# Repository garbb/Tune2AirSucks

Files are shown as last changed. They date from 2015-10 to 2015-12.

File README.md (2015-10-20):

# Tune2AirSucks
This is an attempt to create an interface between the 30pin ipod connector in my car and bluetooth so that I can stream audio from my phone. There exist several commercial products that perform this function, however none of the ones I could find supported displaying song information on my stereo.

It uses a [teensy 3.1](https://www.pjrc.com/teensy/teensy31.html) arduino-comptable board connected to a [BC127 chip] (https://www.sparkfun.com/products/12819) to manage the bluetooth connection.

It will support audio streaming over A2DP and remote control over AVRCP and also transmit song title/artist/album metadata if your phone has AVRCP 1.3 or greater.

The arduino folder contains code to be written to the Teensy with the arduino IDE.<br>
The eagle folder contains schematics and board files needed to make the PCB.<br>
The test folder contains random testing/debugging code such as "ipod.dock.sniffer" which is for sniffing the traffic between an ipod and a dock so I could figure out how it worked.

<br>
Some code/knowledge borrowed/stolen from the following:
* Arduino library for controlling ipods: https://github.com/finsprings/arduinaap<br>
* Purpletooth Jamboree (used for prototyping and used eagle files for audio circuit) https://www.sparkfun.com/products/11924
* BC127 Bluetooth chip arduino library from sparkfun: https://github.com/sparkfun/SparkFun_BC127_Bluetooth_Module_Arduino_Library/

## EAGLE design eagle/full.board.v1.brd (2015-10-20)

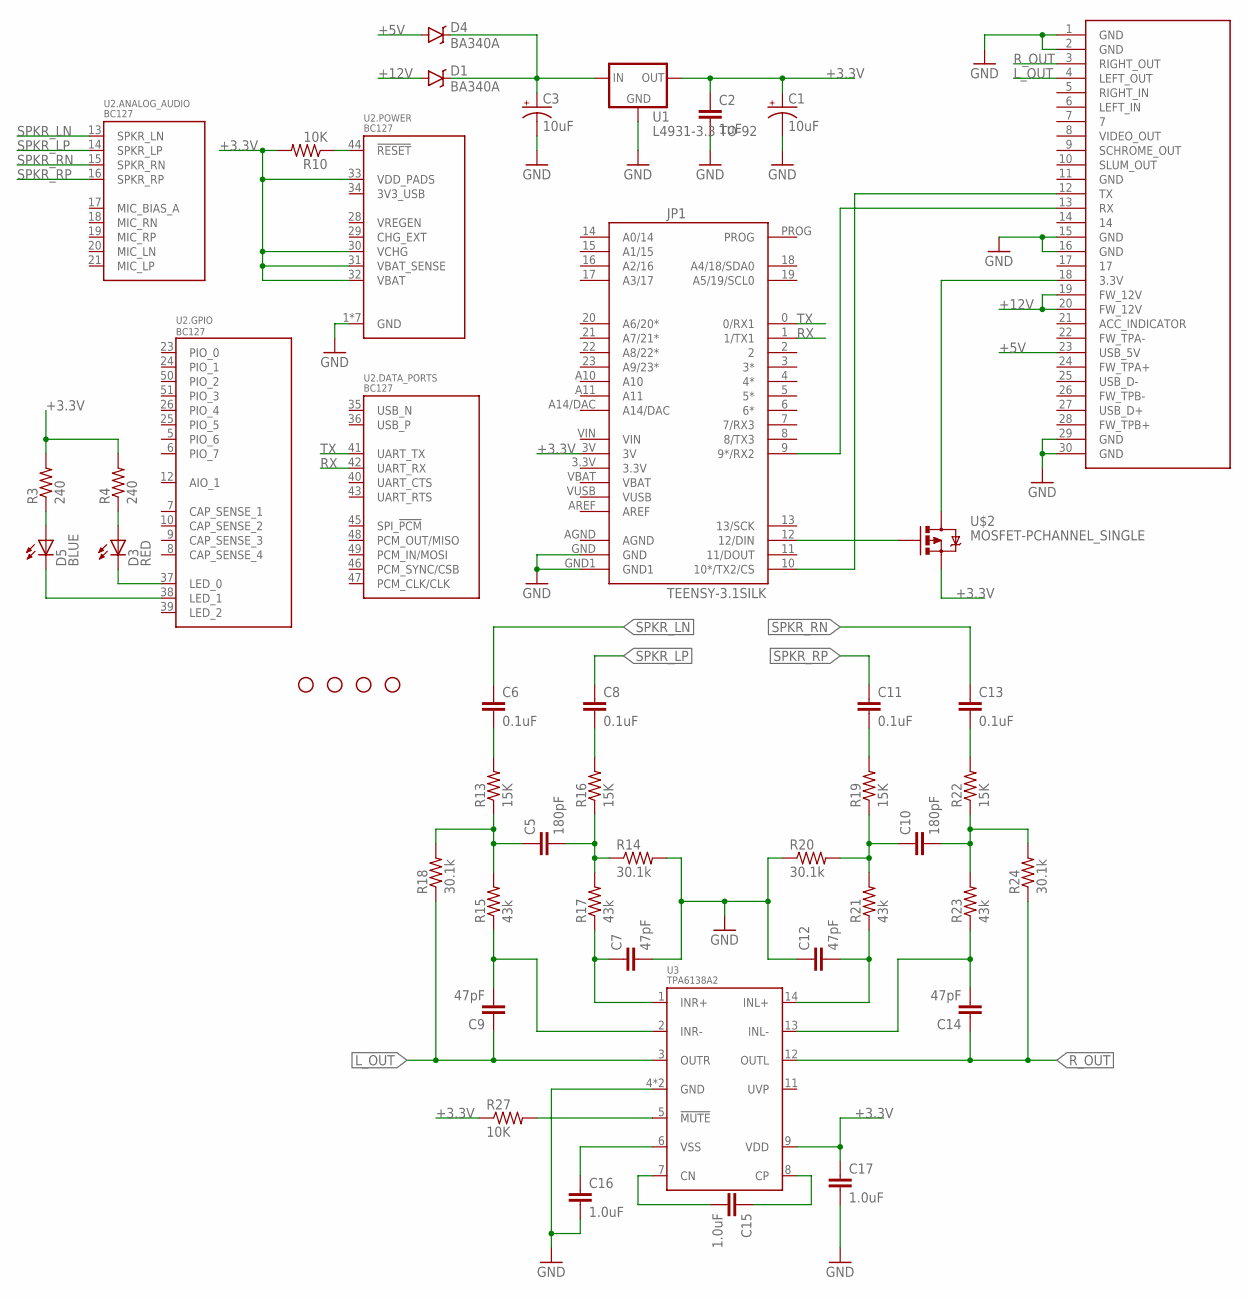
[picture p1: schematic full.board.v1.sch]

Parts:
C1, C3: 10uF; EIA3216
C2: 1uF; 0805
C5, C10: 180pF; 0603-CAP
C6, C8, C11, C13: 0.1uF; 0603-CAP
C7, C9, C12, C14: 47pF; 0603-CAP
C15, C16, C17: 1.0uF; 0603-CAP
D1, D4: BA340A; SMA-DIODE
D3: RED; LED-0603
D5: BLUE; LED-0603
IPOD_CONNECTOR_FEMALE: IPOD_CONNECTOR_FEMALECUTOUT; IPOD_FEM_SM_CUTOUTS
JP1: TEENSY-3.1SILK; TEENSY-3.1
R3, R4: 240; 0603-RES
R10, R27: 10K; 0603-RES
R13, R16, R19, R22: 15K; 0603-RES
R14, R18, R20, R24: 30.1k; 0603-RES
R15, R17, R21, R23: 43k; 0603-RES
STANDOFF1, STANDOFF2, STANDOFF3, STANDOFF4: STAND-OFF
U1: L4931-3.3 TO-92; TO-92
U2: BC127; BC127_XTRA_PASTE
U3: TPA6138A2; TSSOP-14
U$2: MOSFET-PCHANNEL_SINGLE; SOT563-SINGLEFET

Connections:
+3.3V: C1.A (+), C2.1, C17.1, JP1.3V, R3.2, R4.2, R10.2, R27.1, U1.1 (OUT), U2.30 (VCHG), U2.31 (VBAT_SENSE), U2.32 (VBAT), U2.33 (VDD_PADS), U3.9 (VDD), U$2.S
+5V: D4.A, IPOD_CONNECTOR_FEMALE.23 (USB_5V)
+12V: D1.A, IPOD_CONNECTOR_FEMALE.19 (FW_12V), IPOD_CONNECTOR_FEMALE.20 (FW_12V)
GND: C1.C (-), C2.2, C3.C (-), C7.2, C12.1, C16.2, C17.2, IPOD_CONNECTOR_FEMALE.1 (GND), IPOD_CONNECTOR_FEMALE.2 (GND), IPOD_CONNECTOR_FEMALE.15 (GND), IPOD_CONNECTOR_FEMALE.16 (GND), IPOD_CONNECTOR_FEMALE.29 (GND), IPOD_CONNECTOR_FEMALE.30 (GND), JP1.GND, JP1.GND1, R14.2, R20.1, U1.2 (GND), U2.1 (GND), U2.2 (GND), U2.3 (GND), U2.4 (GND), U2.11 (GND), U2.22 (GND), U2.27 (GND), U3.4 (GND), U3.10 (GND)
LED_0: D3.C, U2.37 (LED_0)
LED_1: D5.C, U2.38 (LED_1)
L_OUT: C9.1, IPOD_CONNECTOR_FEMALE.4 (LEFT_OUT), R18.1, U3.3 (OUTR)
unnamed: C3.A (+), D1.C, D4.C, U1.3 (IN)
unnamed: IPOD_CONNECTOR_FEMALE.13 (RX), JP1.9 (9*/RX2)
unnamed: IPOD_CONNECTOR_FEMALE.12 (TX), JP1.10 (10*/TX2/CS)
unnamed: R10.1, U2.44 (!RESET)
unnamed: C8.2, R16.2
unnamed: C6.2, R13.2
unnamed: R27.2, U3.5 (!MUTE)
unnamed: C5.1, R13.1, R15.2, R18.2
unnamed: C9.2, R15.1, U3.2 (INR-)
unnamed: JP1.12 (12/DIN), U$2.G
unnamed: D5.A, R3.1
unnamed: C7.1, R17.1, U3.1 (INR+)
unnamed: C5.2, R14.1, R16.1, R17.2
unnamed: D3.A, R4.1
unnamed: IPOD_CONNECTOR_FEMALE.18 (3.3V), U$2.D1 (D), U$2.D2 (D), U$2.D3 (D), U$2.D4 (D)
unnamed: C10.1, R19.1, R20.2, R21.2
unnamed: C12.2, R21.1, U3.14 (INL+)
unnamed: C11.2, R19.2
unnamed: C10.2, R22.1, R23.2, R24.2
unnamed: C13.2, R22.2
unnamed: C14.2, R23.1, U3.13 (INL-)
unnamed: C16.1, U3.6 (VSS)
unnamed: C15.2, U3.7 (CN)
unnamed: C15.1, U3.8 (CP)
RX: JP1.1 (1/TX1), U2.42 (UART_RX)
R_OUT: C14.1, IPOD_CONNECTOR_FEMALE.3 (RIGHT_OUT), R24.1, U3.12 (OUTL)
SPKR_LN: C6.1, U2.13 (SPKR_LN)
SPKR_LP: C8.1, U2.14 (SPKR_LP)
SPKR_RN: C13.1, U2.15 (SPKR_RN)
SPKR_RP: C11.1, U2.16 (SPKR_RP)
TX: JP1.0 (0/RX1), U2.41 (UART_TX)

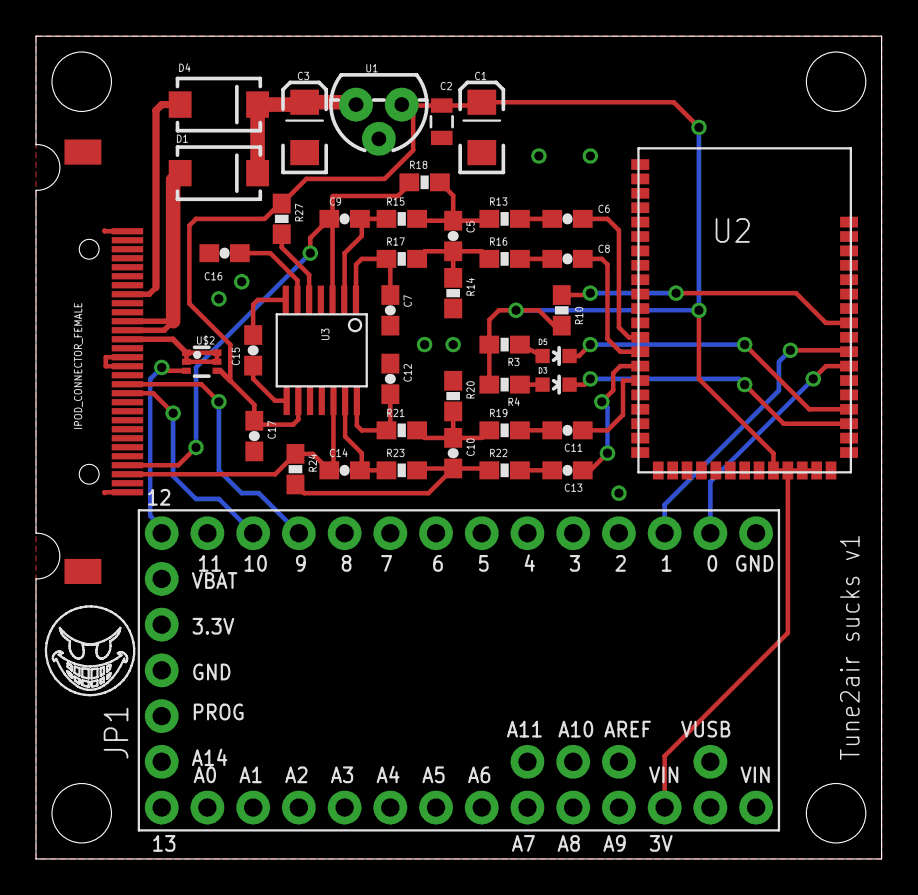
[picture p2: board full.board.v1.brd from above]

Board: 2 copper layers, 47.0 x 45.7 mm, 47 parts (0 on the bottom side), 38 nets.

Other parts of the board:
U$1: EVIL_SMILEY_LOGO

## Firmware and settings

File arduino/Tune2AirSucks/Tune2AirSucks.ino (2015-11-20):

/*
 ******** NEED TO SET THE FOLLOWING PERMAMENT SETTINGS FOR THE BC127 CHIP ONCE
 * SET NAME=Tune2AirSucks
 * SET ENABLE_HFP=OFF
 * SET ENABLE_PBAP=OFF
 * SET AUTOCONN=1
 * SET MAX_REC=0
 * SET CODEC=7 0 1 (to enable all codecs...not sure if this works/maters???)
 * 
 * AND THEN DO "WRITE" AND "RESET"
 */

#define DEBUG
#define DEBUG_SEND    //print out to the debug serial the bytes we are sending with the send_*() functions
const bool send_responses = true; //not really any reason to ever not send anymore?? maybe debugging??
const bool polling_debug = false;

//global variables
extern const String default_trackTitle = "Bluetooth";
extern const String default_trackArtist = "Bluetooth";
extern const String default_trackAlbum = "Bluetooth";
extern String last_trackTitle = "";
extern String last_trackArtist = "";
extern String last_trackAlbum = "";
extern String trackTitle = default_trackTitle;
extern String trackArtist = default_trackArtist;
extern String trackAlbum = default_trackAlbum;

extern bool trackchangeCmdPending = false;
extern bool gotnewArtist = false;
extern bool gotnewAlbum = false;
extern uint32_t albumartistWaitstart = 0;
const uint32_t albumartistTO = 500; //ms

extern bool isWaitingForNewTextRequest = false;
uint32_t newTextRequestWaitstart = 0;
const uint32_t newTextRequestWaitTO = 1000; //ms

//timing for switching 3.3v to ipod connector pin18 to "disconnect/reconnect"
enum CurrentMode
  {
      //WAITING_FOR_1ST_CMD,
      WAITING_FOR_MODE4,
      MODE4,
  };
extern CurrentMode currentMode = WAITING_FOR_MODE4;
uint32_t mode4waitstart = 0;                  //when we started waiting for mode4
const uint32_t mode4timeout = 1000;           //how long to wait until mode4 switch command before we do disconnect/reconnect ;1000
const uint32_t mode4timeoutBootWait = 3000;   //wait at least this long since boot before 1st disconnect/reconnect
uint32_t v_pinLastDisconnectTime = 0;         //time when 3.3v pin was last disconnected
const uint32_t v_pinDisconnectDuration = 600; //time between switching pin off and on ;600
#define v_pinStateON LOW                     //state of output pin to turn on/off voltage on 3.3v pin (will be different if using p-channel mosfet)
#define v_pinStateOFF HIGH
#define v_pin 12
int v_pinState = v_pinStateON;                //state of 3.3v pin; default to ON
int reconnects = 0;                           //current reconnect count
const int maxReconnects = 3;                  //maximum disconnect/reconnect attempts to get it to mode4


extern uint32_t playlistpos = 1;
extern uint32_t trackLength = 3558734;  //nearly 1hr (in case we can't get this info due to older AVRCP)
extern uint32_t trackstarttime = 0;
extern uint32_t accumTrackPlaytime = 0;
enum PlayingState
  {
      STATE_STOPPED = 0x00,
      STATE_PLAYING,
      STATE_PAUSED,
  };
extern PlayingState playingState = STATE_PAUSED;
extern PlayingState prevplayingState = STATE_PAUSED;
extern bool allowPlayPausecmd = true;

extern bool waitingForMetaData = false;
extern String metaDataprevtrackTitle = default_trackTitle;
enum AvrcpReconnectstate {SEND_CLOSE, SEND_OPEN}; AvrcpReconnectstate avrcpReconnectstate = SEND_CLOSE;
extern PlayingState metaDataprevplayingState = STATE_PAUSED;
extern uint32_t metaDataWaitstart = 0;
const uint32_t metaDataWaitTO = 2000; //ms
String cmdstring;

extern uint32_t now = millis();

//teensy3.1 serial pins:
//  Serial1 RX:0, TX:1
//  Serial2 RX:9, TX:10
//  Serial3 RX:7, TX:8
//  Serial is usb emulated serial

#define BC127serial Serial1 //Serial1 RX:0, TX:1

//for debugging (if I want to send commands later to this will need to swap which swserial is .listen()-ing )
#define DebugSerial Serial

//for Tx and Rx to dock
#define DockSerial Serial2  //Serial2 RX:9, TX:10

#include "SimpleTimer.h"
SimpleTimer timer;

#include "myBC127.h"
extern MyBC127 myBC127(BC127serial);
#include "podserialstate.h"


PodserialState dockserialState(DockSerial, "dock->ipod");

const int polling_delay = 500;  //(ms)
uint32_t last_poll = 0;

void setup() {
  //Turn on built-in LED to function as power indicator
  pinMode(13, OUTPUT);
  digitalWrite(13, HIGH);
  
  DebugSerial.begin(115200);    //if teensy usb, baud rate is ignored....
  
  BC127serial.begin(9600);
  DockSerial.begin(19200);
  
  #ifdef DEBUG
    myBC127.setdebugserial(DebugSerial);
    dockserialState.setdebugserial(DebugSerial);
  #endif

//pin for switching 3.3v to ipod connector pin18 to simulate "disconnect/reconnect" of ipod
pinMode(v_pin, OUTPUT);
digitalWrite(v_pin, v_pinState);

  //delay(1000);    //delay is for waiting for teensy usb to become a serial device
  DebugSerial.print("teensy ready\r\n\r\n");
}

void loop() {
  timer.run();
  
  now = millis();
  
  myBC127.readResponses();
  
  dockserialState.process();

  //if ipod polling mode is turned on
  if (dockserialState.pollingmode && now - last_poll > polling_delay) {
    dockserialState.send_response(ADVANCED_REMOTE_MODE, 0x00, RESPONSE_POLLING_MODE, 0x04, 
      playingState==STATE_PLAYING ? ((now - trackstarttime) + accumTrackPlaytime) : accumTrackPlaytime);
    last_poll = now;
  }
  
  //Once we tell the dock that the track has changed, it will request the new track info and we will respond with it.
  //We want to wait and make sure we have the title, artist, album info for the new track before we tell the dock
  //that the track has changed or we might end up sending old info.
  //Also, sometimes we only get title text (no artist or album text) and in this case we will give up waiting and just send it
  //For example we only get title text for pandora advertisements.
  if (trackchangeCmdPending) {
    if ((now - albumartistWaitstart > albumartistTO) || (gotnewArtist && gotnewAlbum)) {
      //if we have no new artist/album info just copy title text
      if (!gotnewArtist) {trackArtist = trackTitle;}
      if (!gotnewAlbum) {trackAlbum = trackTitle;}
      //only reset playing time and increment playlistpos if this is a new track (if title, artist, or album is different)
      if ( (trackTitle != last_trackTitle) || (trackArtist != last_trackArtist) || (trackAlbum != last_trackAlbum) ) {
        trackstarttime = now;  //save track start time as now
        accumTrackPlaytime = 0; //clear accum. track playtime
        //can't tell if next track/prev track/completely different track but it will probably be next track and incrementing playlistpos looks better anyways...
        //also if title is changing from default title to a new title then do not increment playlistpos
        if (last_trackTitle != default_trackTitle && trackTitle != default_trackTitle) {
          (playlistpos < 99) ? playlistpos++ : playlistpos = 1;   //wrap around to 1 if we are at 99 and try to increment
          #ifdef DEBUG
            DebugSerial.print("increment playlistpos. new playlistpos=");DebugSerial.println(playlistpos);
          #endif
        }
      }

      //send track change event and set flag and time to begin waiting for dock to request the new text
      sendTrackChangEvent();
      isWaitingForNewTextRequest = true;
      newTextRequestWaitstart = now;
      
      gotnewArtist = false;
      gotnewAlbum = false;
      trackchangeCmdPending = false;
    }
  }

  //check if we are waiting for dock to request text and it fails to do so within timeout then resend track change event
  if (isWaitingForNewTextRequest && now - newTextRequestWaitstart > newTextRequestWaitTO) {
    #ifdef DEBUG
      DebugSerial.println(">>RESENDING sending track changed event");
    #endif
    sendTrackChangEvent();
    newTextRequestWaitstart = now;
  }

  //if playingstate changed to PLAYING then begin waiting for new metadata
  if (metaDataprevplayingState != playingState) {
    if (playingState == STATE_PLAYING) {
        waitingForMetaData = true;
        metaDataWaitstart = now;
      }
      metaDataprevplayingState = playingState;
  }
  //if we get new track change metadata before metadata timeout then don't do AVRCP reconnect below
  if ((metaDataprevtrackTitle != trackTitle)) {
    if (now - metaDataWaitstart < metaDataWaitTO) {
      waitingForMetaData = false;
    }
    metaDataprevtrackTitle = trackTitle;
  }
  else if (
      (waitingForMetaData) &&
//      (myBC127.BC127_status == myBC127.AVRCP_connected) &&
      (myBC127.AVRCP_linkId != "" && myBC127.AVRCP_address != "") &&
      (now - metaDataWaitstart > metaDataWaitTO)
     )
  {
      if (myBC127.BC127_status == myBC127.AVRCP_connected && avrcpReconnectstate == SEND_CLOSE) {
        #ifdef DEBUG
          DebugSerial.print(now); DebugSerial.println(" metadata wait timeout so re-connecting AVRCP profile");
        #endif
        cmdstring = "CLOSE ";
        cmdstring += myBC127.AVRCP_linkId;
        myBC127.SendCmd(cmdstring);
        avrcpReconnectstate = SEND_OPEN;
      }
      else if (myBC127.BC127_status == myBC127.waiting_for_AVRCP_conn && avrcpReconnectstate == SEND_OPEN) {
        cmdstring = "OPEN ";
        cmdstring += myBC127.AVRCP_address;
        cmdstring += " AVRCP";
        myBC127.SendCmd(cmdstring);
        avrcpReconnectstate = SEND_CLOSE;
        waitingForMetaData = false;
      }
  }

  #ifdef DEBUG
    if (DebugSerial.available()) {
      byte incomingByte = DebugSerial.read();
      //echo
      //DebugSerial.write(incomingByte);
      //allow debug sending of commands to BC127...
      BC127serial.write(incomingByte);
    /*
      //this was for toggling 3.3v on pin18
      if (incomingByte == '1') {
        digitalWrite(v_pin, v_pinStateON); DebugSerial.println("3.3v ON");
      }
      else {
        if (incomingByte == '2') digitalWrite(v_pin, v_pinStateOFF); DebugSerial.println("3.3v OFF");
      }
    */
    /*
      if (incomingByte == '3') {
        v_pinState = v_pinStateOFF;
        digitalWrite(v_pin, v_pinState);
        DebugSerial.println("3.3v OFF");
        v_pinLastDisconnectTime = now;
      }
    */
    }
  #endif

  if (reconnects <= maxReconnects) {
    if ( (currentMode == WAITING_FOR_MODE4) && (v_pinState == v_pinStateON) && (now > mode4timeoutBootWait) && (now - mode4waitstart > mode4timeout) ) {
      v_pinState = v_pinStateOFF;
      digitalWrite(v_pin, v_pinState);
      #ifdef DEBUG
        DebugSerial.println("3.3v OFF");
      #endif
      v_pinLastDisconnectTime = now;
    }
  }

  //3.3v has been switched off, so switch it on after v_pinDisconnectDuration time
  if (v_pinLastDisconnectTime > 0 && (now - v_pinLastDisconnectTime > v_pinDisconnectDuration)) {
    v_pinState = v_pinStateON;
    digitalWrite(v_pin, v_pinState);
    reconnects++;
    #ifdef DEBUG
      DebugSerial.println("3.3v ON");
      DebugSerial.print("reconnect #"); DebugSerial.println(reconnects);
    #endif
    v_pinLastDisconnectTime = 0;    //setting this to 0 indicates that we are currently not (disconnected and in need of reconnection)
    mode4waitstart = now;   //reset timer for waiting for mode4
  }

}

void sendTrackChangEvent() {
  dockserialState.send_response(ADVANCED_REMOTE_MODE, 0x00, RESPONSE_POLLING_MODE, 0x01, playlistpos - 1);
  #ifdef DEBUG
    DebugSerial.println(">>sending track changed event and new track number to ipod dock");
    DebugSerial.print(">>TITLE IS: \""); DebugSerial.print(trackTitle); DebugSerial.println("\"");
    DebugSerial.print(">>ARTIST IS: \""); DebugSerial.print(trackArtist); DebugSerial.println("\"");
    DebugSerial.print(">>ALBUM IS: \""); DebugSerial.print(trackAlbum); DebugSerial.println("\"");
    DebugSerial.println();
  #endif
}

void SendStatusCmd_t() {
  #ifdef DEBUG
    DebugSerial.println("timer status cmd");
  #endif
  myBC127.SendStatusCmd();
}


/*  implement states for bytes received header, length, etc...checksum
    implement timeout (1000ms?)
      actually shouldn't need timeout?? b/c will always get another command and will eventually get bytes to get a full command,
        just need to check checksum and then reject/display error if invalid
    make enum for mode4 commands; 1st byte is always 0, make enum PLAY = 2nd byte value, etc...
    do names for commands w/same number as commands in enum: static const char *STATE_NAME[] =...
    implement debugging for unexpected bytes & bad checksum
    
    make podserialstate class with recievestate enum, buffer for bytes, datasize
    call process() with params: BYREF podserial, serial object to read from, 
*/

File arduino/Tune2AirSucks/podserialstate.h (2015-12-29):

#include "Arduino.h"

//on arduino int is 16-bit(2 byte) and long is 32-bit(4 byte)
//on teensy int is 32bit(4 byte)???
//so replaced all "unsigned long" with uint32_t

const byte MODE_SWITCHING_MODE = 0x00;
const byte SIMPLE_REMOTE_MODE = 0x02;
const byte ADVANCED_REMOTE_MODE = 0x04;

const byte RESPONSE_BAD = 0x00;
const byte RESPONSE_FEEDBACK = 0x01;

//these are commands
//do -1 to make response consts
const byte REQUEST_PROTOCOL_VERSION = 0x12;
const byte RETURN_PROTOCOL_VERSION = 0x13;
const byte CMD_GET_IPOD_NAME = 0x14;
const byte RESPONSE_IPOD_NAME = 0x15;
const byte CMD_SWITCH_TO_MAIN_LIBRARY_PLAYLIST = 0x16;
const byte CMD_SWITCH_TO_ITEM = 0x17;
const byte CMD_GET_ITEM_COUNT = 0x18;
const byte RESPONSE_ITEM_COUNT = 0x19;
const byte CMD_GET_ITEM_NAMES = 0x1A;
const byte RESPONSE_ITEM_NAMES = 0x1B;
const byte CMD_GET_TIME_AND_STATUS_INFO = 0x1C;
const byte RESPONSE_TIME_AND_STATUS_INFO = 0x1D;
const byte CMD_GET_PLAYLIST_POSITION = 0x1E;
const byte RESPONSE_PLAYLIST_POSITION = 0x1F;
const byte CMD_GET_TITLE = 0x20;
const byte RESPONSE_TITLE = 0x21;
const byte CMD_GET_ARTIST = 0x22;
const byte RESPONSE_ARTIST = 0x23;
const byte CMD_GET_ALBUM = 0x24;
const byte RESPONSE_ALBUM = 0x25;
const byte CMD_POLLING_MODE = 0x26;
const byte RESPONSE_POLLING_MODE = 0x27;
const byte CMD_EXECUTE_SWITCH = 0x28;
const byte CMD_PLAYBACK_CONTROL = 0x29;
const byte CMD_GET_SHUFFLE_MODE = 0x2C;
const byte RESPONSE_SHUFFLE_MODE = 0x2D;
const byte CMD_SET_SHUFFLE_MODE = 0x2E;
const byte CMD_GET_REPEAT_MODE = 0x2F;
const byte RESPONSE_REPEAT_MODE = 0x30;
const byte CMD_SET_REPEAT_MODE = 0x31;
const byte CMD_PIC_BLOCK = 0x32;
const byte CMD_GET_PIC_SIZE = 0x33;
const byte RESPONSE_PIC_SIZE = 0x34;
const byte CMD_GET_SONG_COUNT_IN_CURRENT_PLAYLIST = 0x35;
const byte RESPONSE_SONG_COUNT_IN_CURRENT_PLAYLIST = 0x36;
const byte CMD_JUMP_TO_SONG_IN_CURRENT_PLAYLIST = 0x37;

enum itemType
  {
      TYPE_PLAYLIST = 0x01,
      TYPE_ARTIST,
      TYPE_ALBUM,
      TYPE_GENRE,
      TYPE_SONG,
      TYPE_COMPOSER
  };
  
enum feedbackResult
  {
      RESULT_SUCCESS = 0x00,
      RESULT_FAILURE = 0x02,
      RESULT_LIMIT_EXCEEDED = 0x04,
      RESULT_SEND_RESPONSE = 0x04,
  };

#if defined(DEBUG)
  const char* const mode4CmdNames[0x3A] = {
    /*0x00*/ "BAD command",
    /*0x01*/ "FEEDBACK",
    /*0x02*/ "ping?",
    /*0x03*/ "pong?",
    /*0x04*/ "??",
    /*0x05*/ "??",
    /*0x06*/ "??",
    /*0x07*/ "??",
    /*0x08*/ "??",
    /*0x09*/ "??",
    /*0x0A*/ "??",
    /*0x0B*/ "??",
    /*0x0C*/ "??",
    /*0x0D*/ "??",
    /*0x0E*/ "??",
    /*0x0F*/ "??",
    /*0x10*/ "??",
    /*0x11*/ "??",
    /*0x12*/ "RequestProtocolVersion",
    /*0x13*/ "ReturnProtocolVersion",
    /*0x14*/ "get ipod name",
    /*0x15*/ "ipod name response:",
    /*0x16*/ "switch to main library",
    /*0x17*/ "switch to ",
    /*0x18*/ "get count of ",
    /*0x19*/ "count response",
    /*0x1A*/ "get names of ",
    /*0x1B*/ "names response",
    /*0x1C*/ "get time/status",
    /*0x1D*/ "time/status response: ",
    /*0x1E*/ "get plist pos",
    /*0x1F*/ "playlist position is ",
    /*0x20*/ "get title of song #",
    /*0x21*/ "title response:",
    /*0x22*/ "get artist of song #",
    /*0x23*/ "artist response:",
    /*0x24*/ "get album of song #",
    /*0x25*/ "album response:",
    /*0x26*/ "polling start/stop",
    /*0x27*/ "polling response",
    /*0x28*/ "switch to plist",
    /*0x29*/ "playback control cmd ",
    /*0x2A*/ "??",
    /*0x2B*/ "??",
    /*0x2C*/ "get shuffle mode",
    /*0x2D*/ "shuffle mode response",
    /*0x2E*/ "set shuffle mode",
    /*0x2F*/ "get repeat mode",
    /*0x30*/ "repeat mode response",
    /*0x31*/ "set repeat mode",
    /*0x32*/ "picture block",
    /*0x33*/ "get pic size?",
    /*0x34*/ "pic size response?",
    /*0x35*/ "get # of songs",
    /*0x36*/ "# of songs response",
    /*0x37*/ "jump to song #",
    /*0x38*/ "??",
    /*0x39*/ "??"
  };
#endif

//char buffer[30];  //buffer needed to read strings out of program flash memory

class PodserialState {
  public:

  uint32_t currentBufferpos;
  static const uint32_t dataBufferSize = 2048;  //hopefully big enough for packets with 2byte data size??
  byte dataBuffer[dataBufferSize];
  uint32_t dataSize;
  byte receivedchecksum;
  byte checksum;
  byte mode;
  byte command[2];
  uint32_t paramsize;
  byte *pParambytes;
  bool gotextraB;
  bool maybeheader;
  char const *streamName;
  bool pollingmode = false;
  int start_num_to_get = 0;
  int num_of_items_to_get = 0;

  Stream *pSerial;
  Stream *myDebugSerial;

  enum ReceiveState
      {
          WAITING_FOR_HEADER1 = 0,
          WAITING_FOR_HEADER2,
          WAITING_FOR_LENGTH0,
          WAITING_FOR_LENGTH1,
          WAITING_FOR_LENGTH2,
          WAITING_FOR_DATA,
          WAITING_FOR_CHECKSUM
      };
  ReceiveState receiveState;
  
  enum Shufflemode
    {
        SHUFFLE_OFF = 0x00,
        SHUFFLE_SONGS = 0x01,
        SHUFFLE_ALBUMS = 0x02,
    };
  Shufflemode shufflemode = SHUFFLE_OFF;

  enum Repeatmode
    {
        REPEAT_OFF = 0x00,
        REPEAT_ONE_SONGS = 0x01,
        REPEAT_ALL_SONGS = 0x02,
    };
  Repeatmode repeatmode = REPEAT_OFF;

  PodserialState(Stream &newiPodSerial, char const *newstreamName);

  void process();
  void setdebugserial(Stream &newDebugSerial);
  
  byte validChecksum();
  uint32_t endianConvert(const byte *p);

  void send_feedback(byte cmd_this_is_feedback_for, byte result);

  void send_response(byte mode, byte cmdbyte1, byte cmdbyte2);
  void send_response(byte mode, byte cmdbyte1, byte cmdbyte2, const byte *pData, byte paramlength);
  void send_response(byte mode, byte cmdbyte1, byte cmdbyte2, uint32_t num1, uint32_t num2, byte statusbyte);
  void send_response(byte mode, byte cmdbyte1, byte cmdbyte2, uint32_t num1);
  void send_response(byte mode, byte cmdbyte1, byte cmdbyte2, byte pollingbyte, uint32_t num1);
  void send_response(byte mode, byte cmdbyte1, byte cmdbyte2, String string);
  void send_response(byte mode, byte cmdbyte1, byte cmdbyte2, uint32_t num1, String string);

  void sendHeader();
  void sendNumber(uint32_t n);
  void sendChecksum();
  void sendByte(byte b);
};
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

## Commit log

2015-07-20 wait for AVRCP connection before sending play/pause cmds
    also bug: don't set status to AVRCP_connected when getting A2DP
    connection
    [myBC127.h, podserialstate.h]
2015-07-22 track change event resend if no text request
    resend track change event to dock if dock does not request song text
    within timeout period (currently 1sec)
2015-07-28 AVRCP reconnect to force metadata
    Implemented AVRCP reconnect when playstate changes to playing in order
    to coax stubborn devices to send metadata. Also made default text
    "Bluetooth" a constant var.
    [bt.to.ipod.dock.fzz]
2015-08-17 inc plist pos upon new track and 1->99 wrap
    increment playlist position upon getting new track text. Also wrap
    around playlist position to 99 if it is 1 and we --
    Also init playlist position to 1.
2015-08-20 schematic change
    [bt.to.ipod.dock.fzz]
2015-08-30 only reset playing time if new track
    only reset playing time if this is a new track (if title, artist, or
    album is different)
    [myBC127.h, podserialstate.h]
2015-09-28 dock pin18 3.3v toggle to coax mode4
2015-09-28 teensy ready
2015-09-29 perm settings comment
    [bt.to.ipod.dock.fzz]
2015-10-04 swap states for 3.3v pin toggle for p-ch mosfet
    swap LOW-HIGH states for 3.3v pin toggle for p-ch mosfet
2015-10-20 3.3v mosfet pin change for pcb
2015-10-20 Folder re-org, inc. eagle files
    [bt.to.ipod.dock.fzz, full.board.v1.brd, full.board.v1.sch]
2015-10-20 rename arduino folder
2015-10-20 arduino IDE is dumb and requires extra folder
2015-11-10 csum in string bug and send interface v1.00
    [podserialstate.h]
2015-11-20 teensy power light
2015-12-29 recompute text string length
    recompute text string length if leading space is added as workaround for
    checksum-in-string dock bug
    [podserialstate.h]
2015-12-29 replace unicode apostrophe
    text from bluetooth is a unicode "RIGHT SINGLE QUOTATION MARK" instead
    of an ascii single quote/apostrophe char but my car can't handle unicode
    so let's replace it
    [podserialstate.h]

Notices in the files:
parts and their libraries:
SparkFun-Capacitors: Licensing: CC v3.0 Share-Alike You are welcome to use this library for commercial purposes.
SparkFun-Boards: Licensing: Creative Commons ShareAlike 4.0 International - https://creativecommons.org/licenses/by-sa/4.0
